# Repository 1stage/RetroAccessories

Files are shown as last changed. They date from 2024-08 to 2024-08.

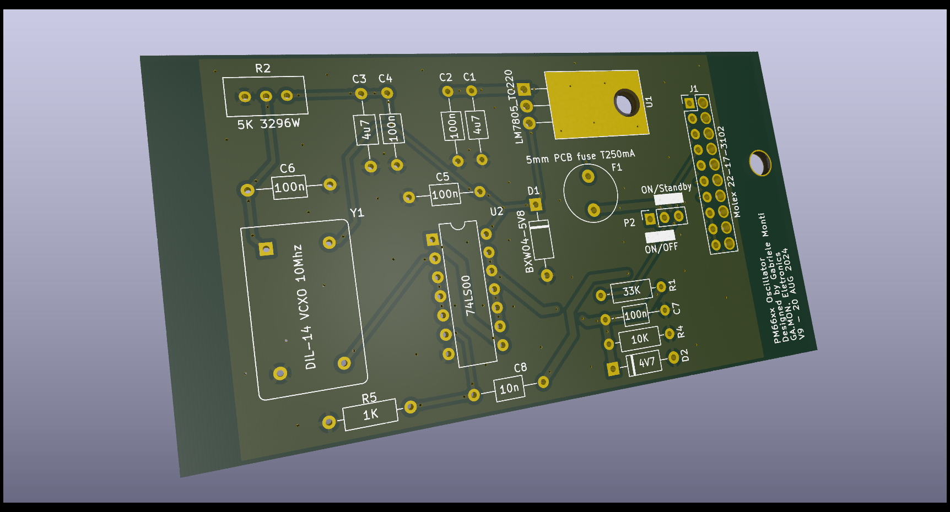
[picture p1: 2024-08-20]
cad/oscillator/oscillator_v9_pcb.png

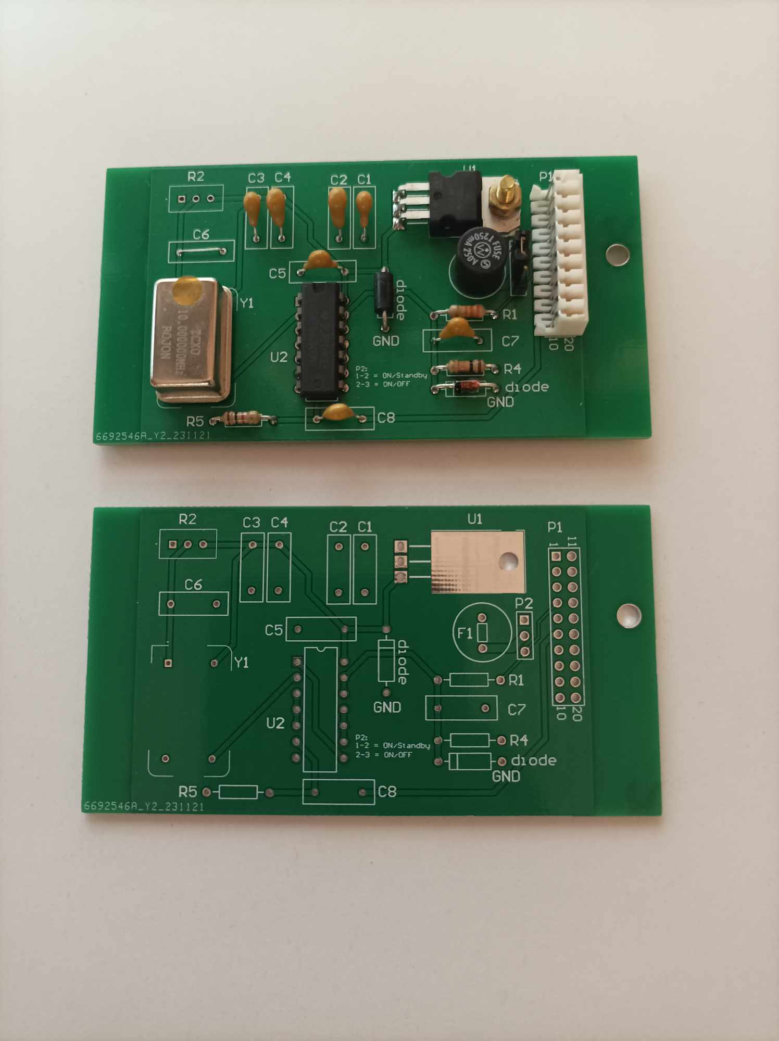
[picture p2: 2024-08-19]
source/oscillator/Oscillator_Fin_V8.jpg

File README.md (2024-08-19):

# RetroAccessories
**Add-ons and accessories for retro computers by GaMon Electronics**

In Summer of 2024, GaMon approached me with the task of turning their concept sketches into CAD files that others could enjoy and use. As we had several shared interests, I agreed and began the process of "digitizing" their content.

I'll keep you updated as to my progress...

- Sean Harrington

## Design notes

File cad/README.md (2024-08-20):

# CAD Files
This folder contains the project files for each project that has been drafted into KiCAD.

These projects use [KiCAD Version 8](https://www.kicad.org/).

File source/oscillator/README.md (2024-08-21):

10Mhz Time Base oscillator for Philips PM instruments.

This little project is intended for all the owners of Philips "PM66xx" family Frequency Meters and Counters, who need to upgrade or replace one of the following time-base oscillators fitted in those instruments:

_ PM9677
_ PM9678
_ PM9679
_ PM9690

This new PCB respects the original module's connections, dimensions, and mechanical fastening, to garantee a direct replacement without modifications.
It can be equipped with any kind of industrial integrated oscillators in DIL-14 case, either TCXO and VCXO types.

A jumper allow to choose 2 operating modes:

1) "ON/STANDBY" mode: oscillator is always running taking supply from intrument's battery charger to maintain temperature and stability, and the output state is switched on/off by the main power switch on front panel (Recommended default).
2) "ON/OFF" mode: both oscillator and output are powered from the main power switch (Power saving mode, for portable use in battery supply).

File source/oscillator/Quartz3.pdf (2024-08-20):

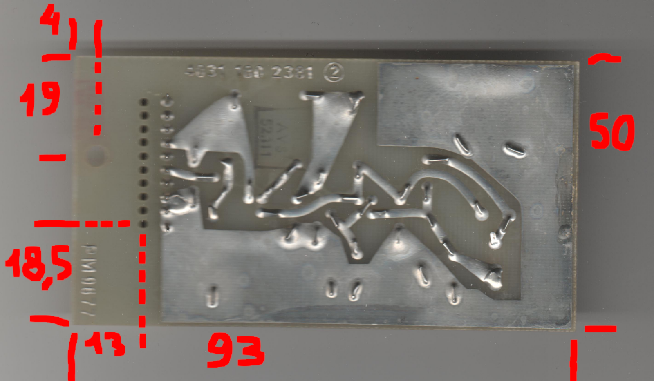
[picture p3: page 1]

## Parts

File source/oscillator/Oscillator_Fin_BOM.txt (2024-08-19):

Philips PM66xx Oscillator BOM:

_ R1 : Axial 33Kohm 1/4W (reduce to 27Kohm if output have difficulties to resume from standby)
_ R2 : 5Kohm vertical 10 turns trimmer (Bourns 3296W or similar)
_ R4 : Axial 10Kohm 1/4W
_ R5 : Axial 1Kohm 1/4W

_ C1 : 100nF 50V MLCC
_ C2 : 4.7uF 25V Tantalum (or MLCC)
_ C3 : 4.7uF 25V Tantalum (or MLCC)
_ C4 : 100nF 50V MLCC
_ C5 : 100nF 50V MLCC
_ C6 : 100nF 50V MLCC
_ C7 : 100nF 50V MLCC
_ C8 : 10nF 50V MLCC

_ D1 : BZW04-5V8 (or equivalent unidirectional 5.8V TVS diode)
_ D2 : 1N5230 (or equivalent 4.7V 0.5W Zener diode)

_ U1 : LM7805 or uA7805 or KA7805 (TO-220 case)
_ U2 : 74LS00 or 74HCT00 or 74F00 or 74AHCT00 (NO 74HC00 or 74C00)

_ Y1 : 10Mhz VCXO or TCXO in DIL-14 case

_ F1 : T250mA 5mm THT Fuse

_ J1 : MOLEX 22-17-3102 (10pin 2.54mm female connector)

_ P2 : 3pin 2.54mm male pin-strip

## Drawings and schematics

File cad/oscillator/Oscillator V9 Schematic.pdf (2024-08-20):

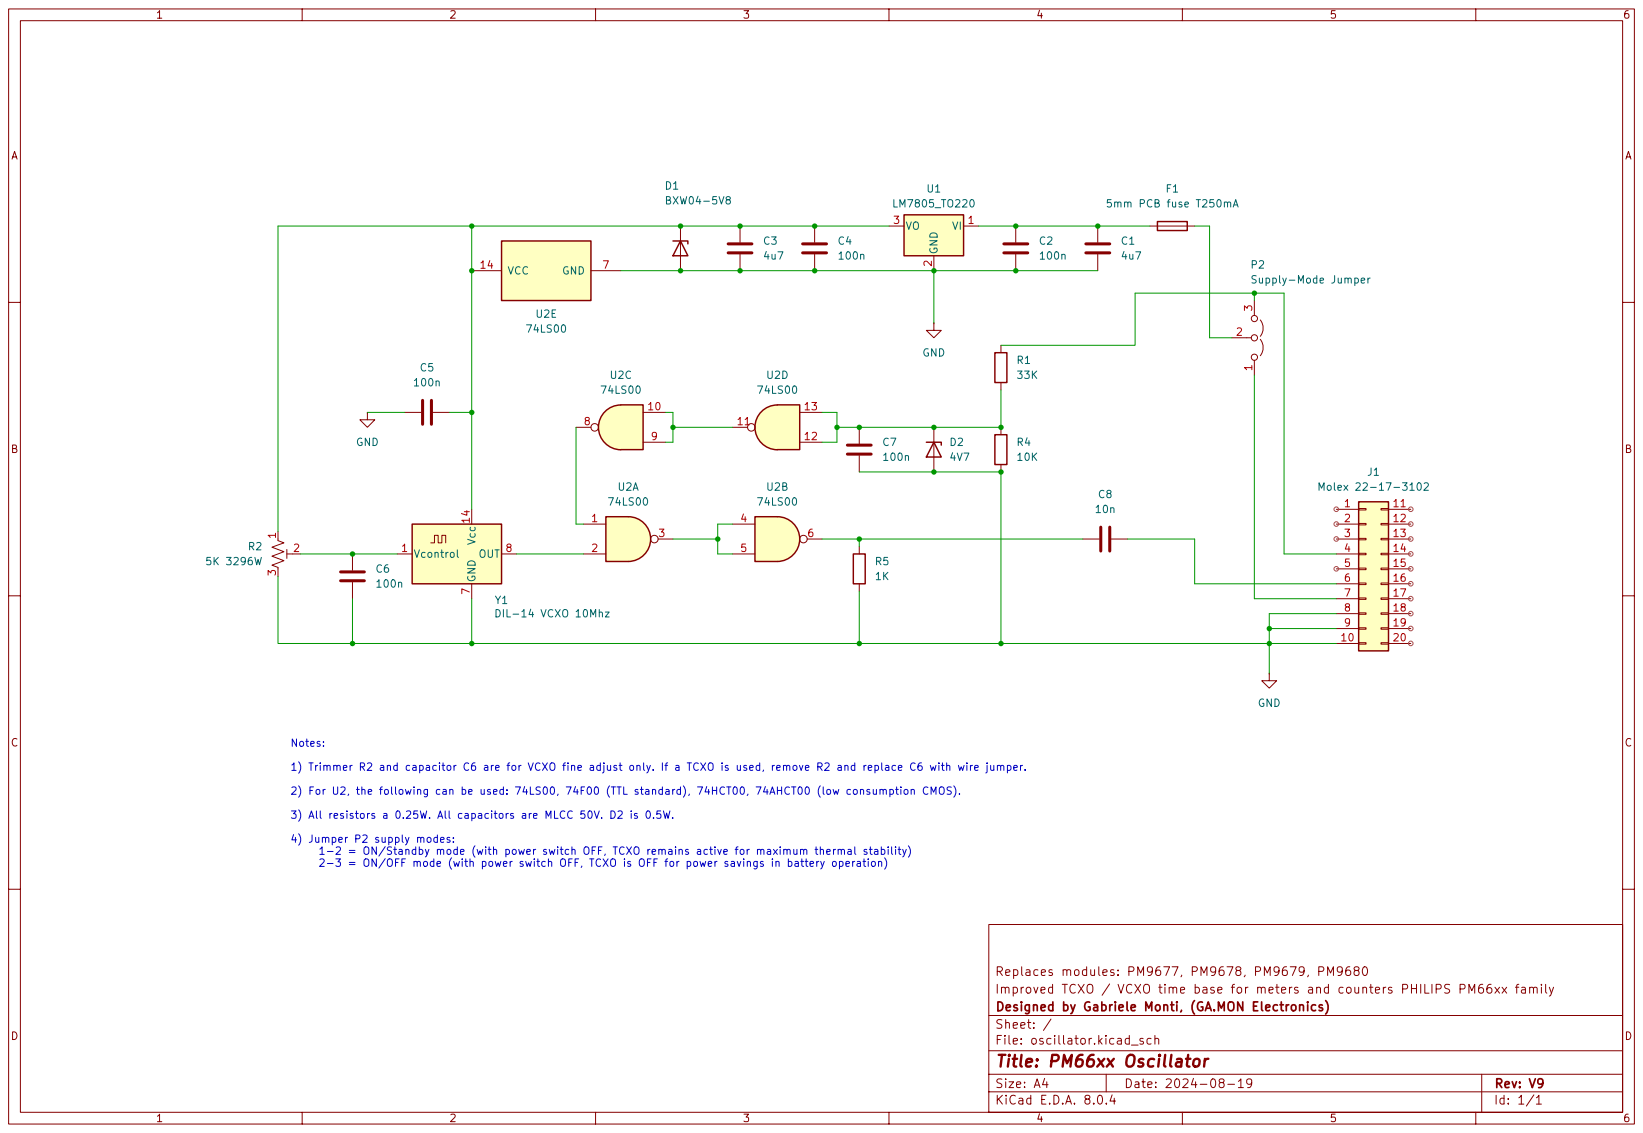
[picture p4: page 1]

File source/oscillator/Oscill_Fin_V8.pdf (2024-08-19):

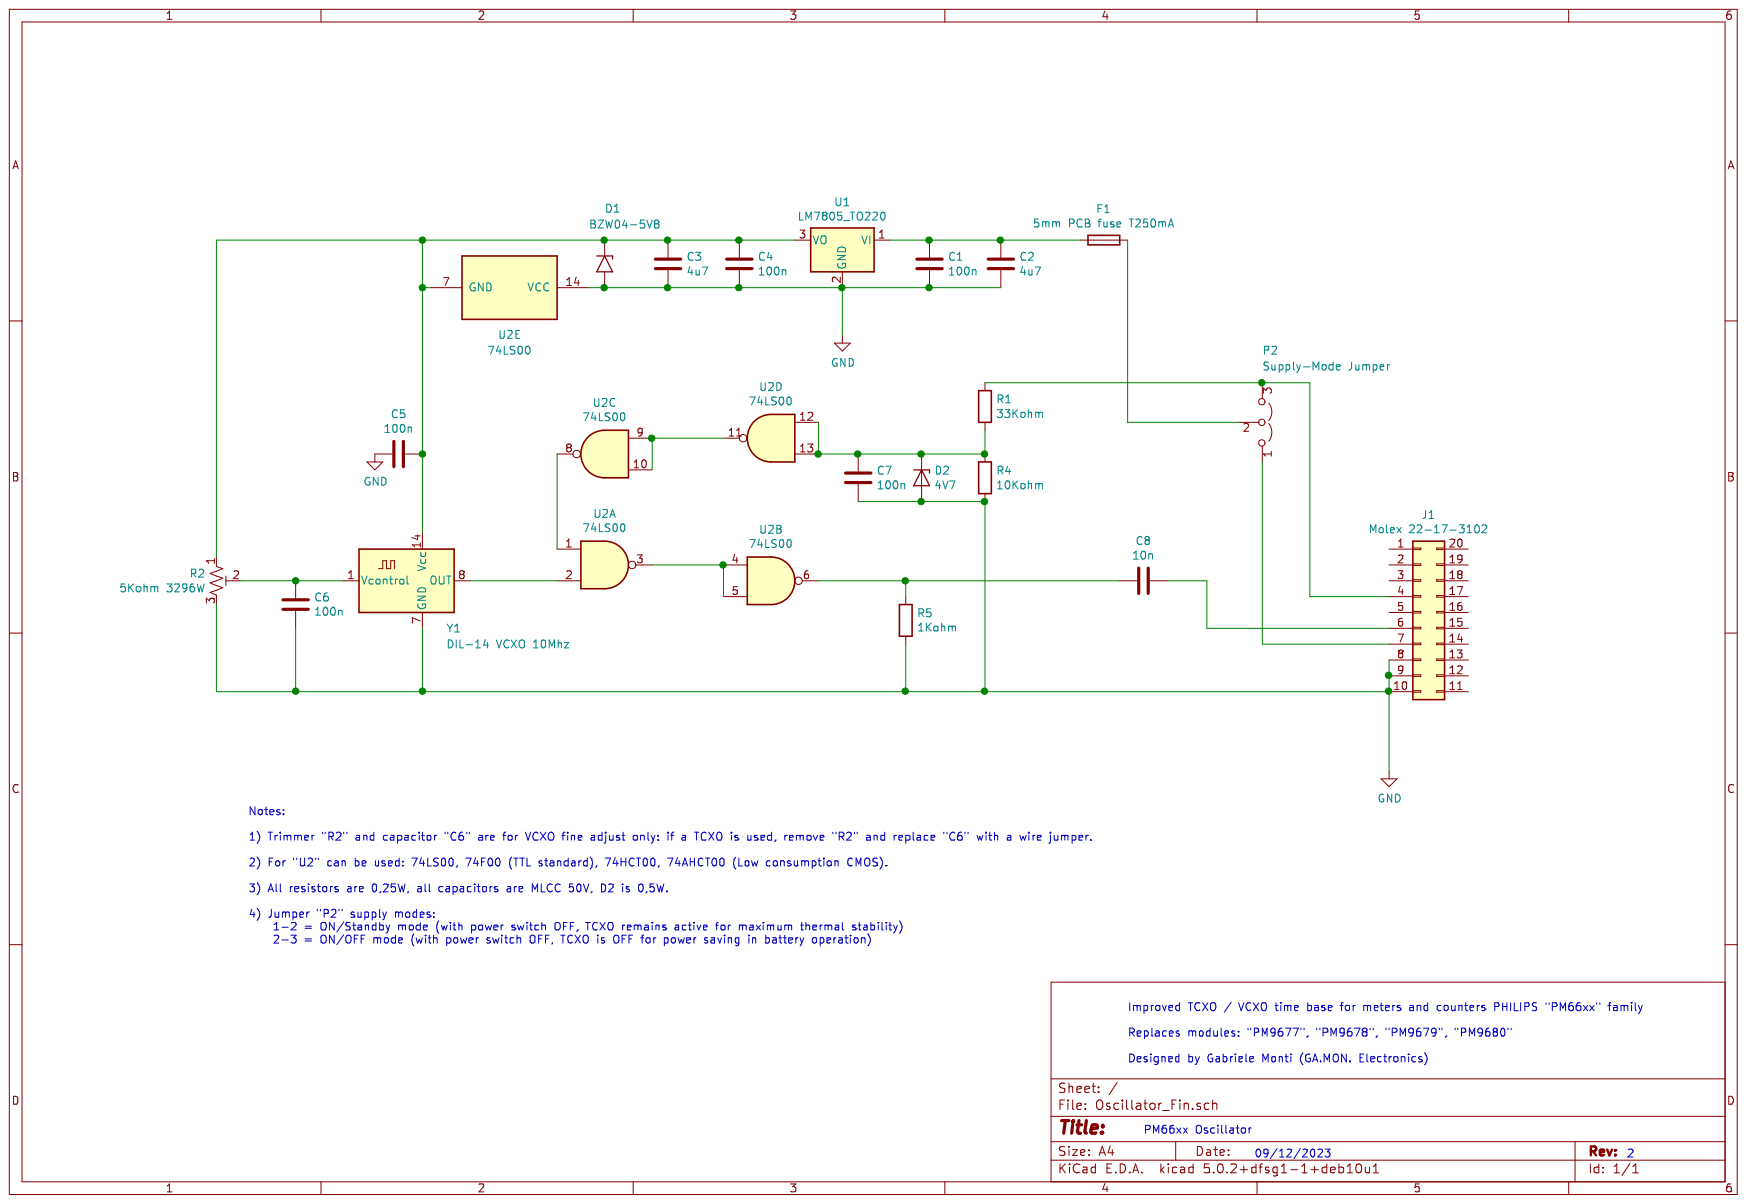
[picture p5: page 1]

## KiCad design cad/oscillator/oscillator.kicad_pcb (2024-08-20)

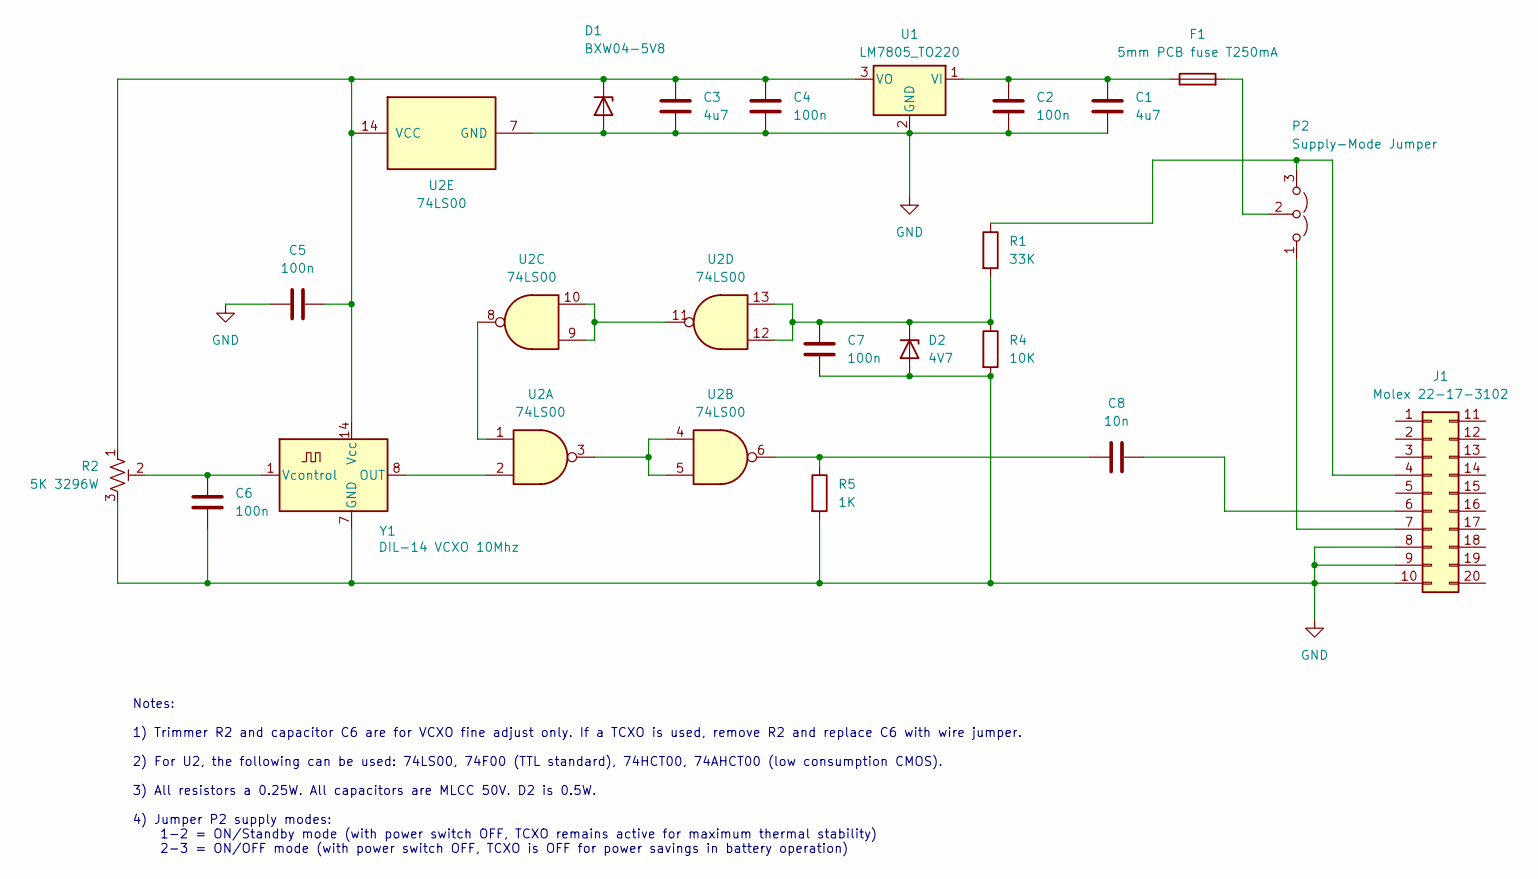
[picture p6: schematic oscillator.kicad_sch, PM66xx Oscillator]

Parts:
C1, C3: 4u7; C_Axial_L3.8mm_D2.6mm_P10.00mm_Horizontal
C2, C4, C5, C6, C7: 100n; C_Axial_L3.8mm_D2.6mm_P10.00mm_Horizontal
C8: 10n; C_Axial_L3.8mm_D2.6mm_P10.00mm_Horizontal
D1: BXW04-5V8; D_A-405_P10.16mm_Horizontal
D2: 4V7; D_A-405_P10.16mm_Horizontal
F1: 5mm PCB fuse T250mA; Fuse_Littelfuse_372_D8.50mm
J1: Molex 22-17-3102; PinHeader_2x10_P2.54mm_Vertical
P2: Supply-Mode Jumper; PinSocket_1x03_P2.54mm_Vertical
R1: 33K; R_Axial_DIN0207_L6.3mm_D2.5mm_P10.16mm_Horizontal
R2: 5K 3296W; Potentiometer_Bourns_3296W_Vertical
R4: 10K; R_Axial_DIN0207_L6.3mm_D2.5mm_P10.16mm_Horizontal
R5: 1K; R_Axial_DIN0207_L6.3mm_D2.5mm_P10.16mm_Horizontal
U1: LM7805_TO220; TO-220-3_Horizontal_TabDown
U2: 74LS00; CERDIP-14_W7.62mm_SideBrazed
Y1: DIL-14 VCXO 10Mhz; Oscillator_DIP-14

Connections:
GND: C1.2, C2.2, C3.2, C4.2, C5.1, C6.2, C7.2, D1.2 (A), D2.2 (A), J1.8, J1.9, J1.10, R2.3, R4.2, R5.2, U1.2 (GND), U2.7 (GND), Y1.7 (GND)
unnamed: C8.1, R5.1, U2.6
unnamed: C3.1, C4.1, C5.2, D1.1 (K), R2.1, U1.3 (VO), U2.14 (VCC), Y1.14 (Vcc)
unnamed: C7.1, D2.1 (K), R1.2, R4.1, U2.12, U2.13
unnamed: J1.4, P2.3 (B), R1.1
unnamed: C8.2, J1.6
unnamed: J1.7, P2.1 (A)
unnamed: F1.2, P2.2 (C)
unnamed: C1.1, C2.1, F1.1, U1.1 (VI)
unnamed: U2.1, U2.8
unnamed: U2.3, U2.4, U2.5
unnamed: U2.9, U2.10, U2.11
unnamed: U2.2, Y1.8 (OUT)
unnamed: C6.1, R2.2, Y1.1 (Vcontrol)

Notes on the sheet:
Notes: 1) Trimmer R2 and capacitor C6 are for VCXO fine adjust only. If a TCXO is used, remove R2 and replace C6 with wire jumper. 2) For U2, the following can be used: 74LS00, 74F00 (TTL standard), 74HCT00, 74AHCT00 (low consumption CMOS). 3) All resistors a 0.25W. All capacitors are MLCC 50V. D2 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

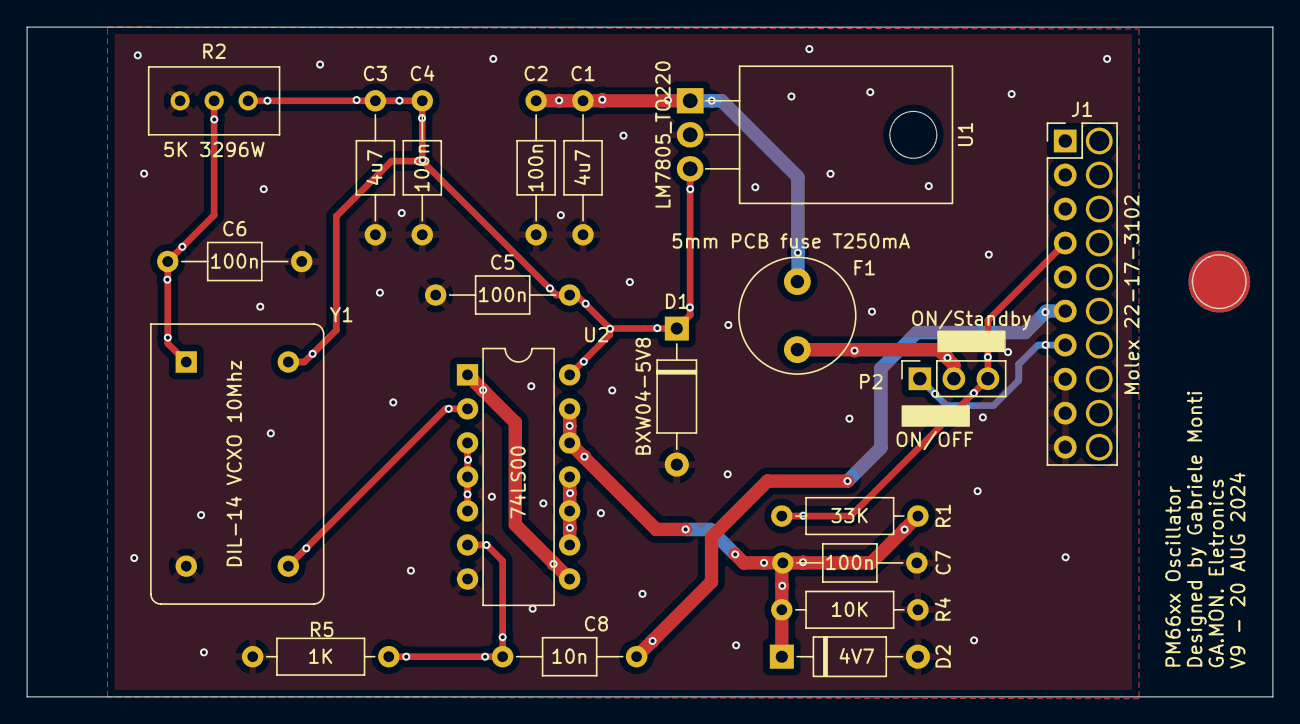
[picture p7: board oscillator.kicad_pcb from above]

Board: 2 copper layers, 93.0 x 50.0 mm, 20 parts (0 on the bottom side), 14 nets.

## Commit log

2024-08-19 Add files via upload
    This little project is intended for all the owners of Philips "PM66xx" family Frequency Meters and Counters, who need to upgrade or replace one of the following time-base oscillators fitted in those instruments:
    _ PM9677
    _ PM9678
    _ PM9679
    _ PM9690
    This new PCB respects the original module's connections, dimensions, and mechanical fastening, to garantee a direct replacement without modifications.
    It can be equipped with any kind of industrial integrated oscillators in DIL-14 case, either TCXO and VCXO types.
    A jumper allow to choose 2 operating modes:
    1) "ON/STANDBY" mode: oscillator is always running taking supply from intrument's battery charger to maint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
2024-08-20 Started Oscillator CAD Test
    [oscillator.kicad_pcb, oscillator.kicad_sch]
2024-08-20 Oscillator Updates
    [oscillator.kicad_pcb, oscillator.kicad_sch]
2024-08-20 Oscillator V9 Updates
    [oscillator.kicad_pcb]
